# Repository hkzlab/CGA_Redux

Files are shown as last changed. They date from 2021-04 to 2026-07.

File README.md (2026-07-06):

# Color Graphics Adapter - Redux

## Introduction

The Color Graphics Adapter (**CGA**) Redux board is a more or less faithful clone of the original IBM CGA, based on the original schematics.

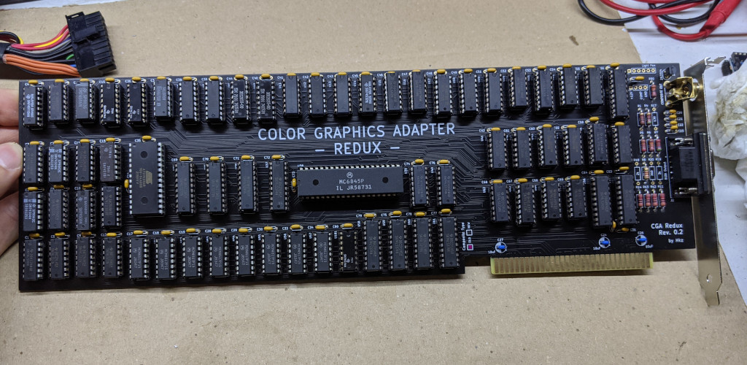
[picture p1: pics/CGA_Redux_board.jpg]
CGA Redux


Since revision 0.2 of this board, **You can decide to build it with the "new" or "old" style composite output**, giving you slightly different colours.

Have a look [HERE](https://int10h.org/blog/2015/08/8088-mph-final-old-vs-new-cga-gory-details/) for a blog post that discusses the difference in regard to the famous **8088MPH** demo!

### Disclaimer

I take NO responsibility for what happens if you decide to build and use this card. Your computer might crash, catch fire or be destroyed in other nasty ways.
You're encourauged to take what you deem fit from this, and use it in your projects!

### Functionalities

✅ means I tested the functionality and it works, ❌ means I tested the functionality and found issues, ? means that the functionality has yet to be tested.

* [✅] Digital display in text mode, 40 columns
* [✅] Digital display in text mode, 80 columns
* [✅] Composite display in text mode, 40 columns
* [✅] Composite display in text mode, 80 columns
* [✅] Graphics mode in digital
* [✅] Graphics mode in composite
* [✅] Run CheckIt video test
* [✅] 8088MPH Demo
* [?] Light pen input

## Bill of Materials

| Component | Qty | Type / Value |
| --- | --- | --- |
| **TODO** | | |

### Character ROM

This board needs a character ROM to work. I would advise to search for a dump of IBM P/N 5788005, concatenate it four times and burn it on a 27C256 EPROM.

### Component substitutions

* U4,U5 and U101 should all be 'S174s, but I had only 'LS174 available. The board looks to be working without issues anyway
* U50-U57 are all 120ns DRAMs in my original board. I had only 150ns chips for this build, and they worked fine
* U9,U10 are 74153 chips. I tried to replace them with 74LS153 chips by Texas Instruments with good results. **Needs some testing with colored screens**
* U50-U57 can be substituted by 41256 / 4164 DRAMs like the M5K4164 or HM4864P (the additional address lines are grounded). **Tested with HM4864P**

## Support

If you wish to support me in building new hardware and software for old machines, [throw a few euros in my direction via Ko-Fi](https://ko-fi.com/hkzlab) ☕!

### 💰 Selling these boards 💰

I you want to contact me about selling this project, you can reach me via email at `0hkzUNDERSCOREprojects6ATposteoDOTnet` after properly fixing the email address by removing the digits and replacing the uppercase words with the proper characters.

**Contacts via other channels will be ignored**, as it means you did not read this document thoroughly.

"Collaborations" will boil down to the following:

- If you wish to produce and share this project at a loss or at cost, go for it. I am only asking for attribution and to let me know via email.
- If you want to do it for profit, let's discuss it. I'll probably settle for a rough 5% of the profit. Importing components is getting more expensive by the day, so this will contribute to me making future projects available for free.
- I will NOT do customer assistance for you or your customers. This is a hobby, not my job.

If this is not ok for you, you're cordially invited to go bother someone else :)

Authorized sellers will be listed in this README. If you find someone selling my boards without being listed here, it means they're stealing other people's work.

## Known issues

### Rev 0

* The Composite video out has an inverted connection for that type of footprint. (fixed in rev 0.1)
* Silkscreen for U28 says 74LS10, but it's actually an 74S10 on an original board (fixed in rev 0.1)
* traces that connect the edge to the power planes for 5V and GND are a bit too thin for my taste (fixed in rev 0.1)

## TODO

* ???

## Credits

Thanks to [Sergey Kiselev](https://github.com/skiselev) for his symbol/footprint library!

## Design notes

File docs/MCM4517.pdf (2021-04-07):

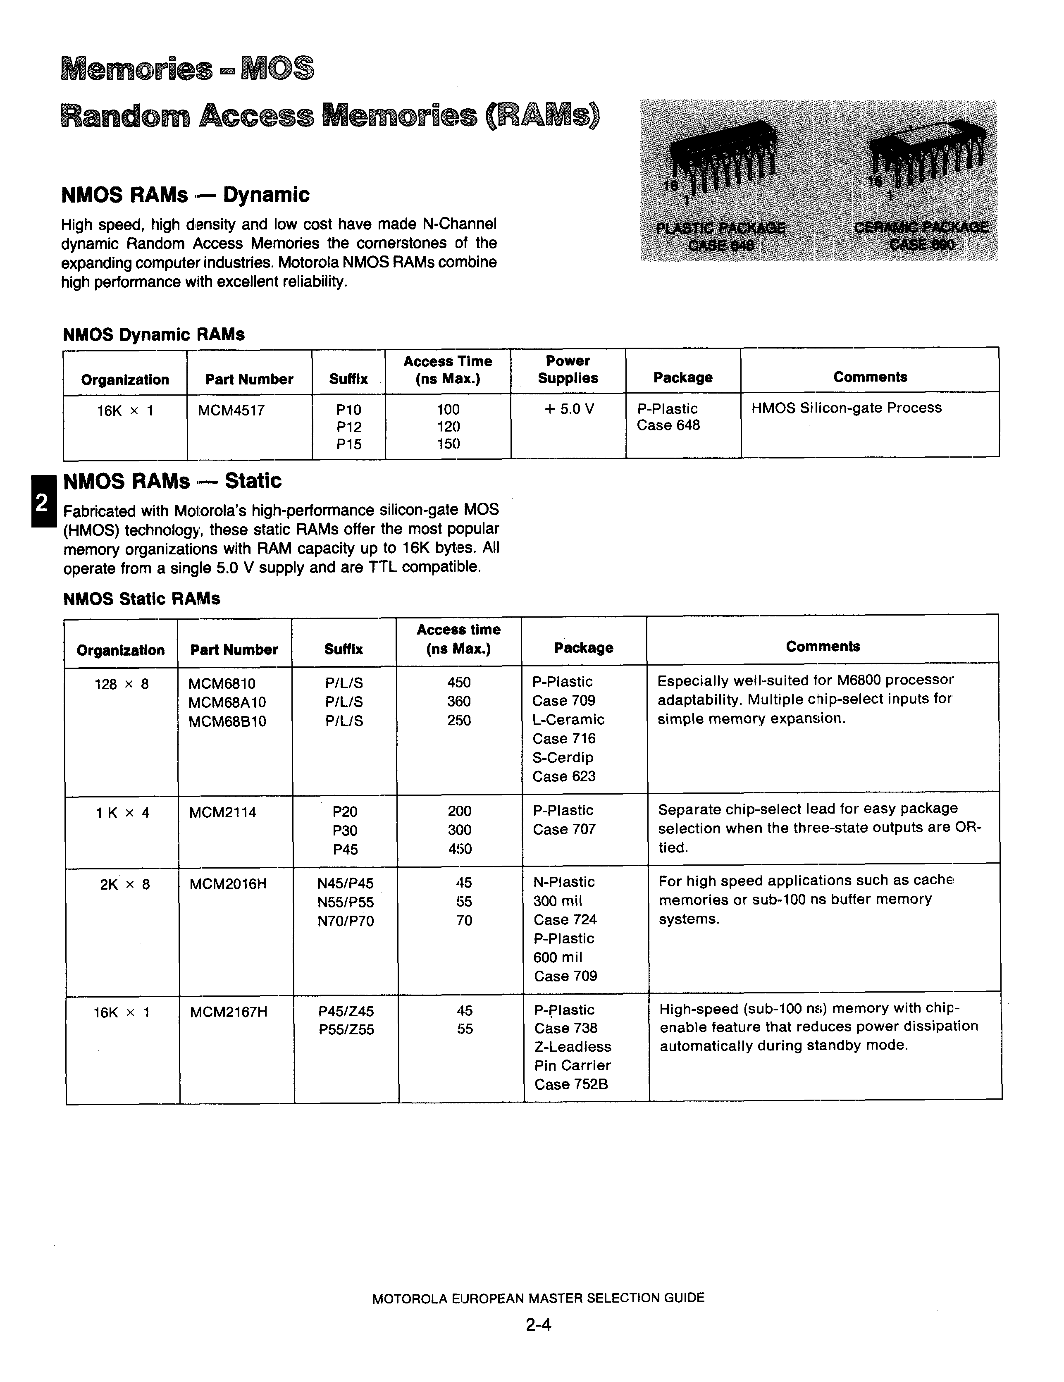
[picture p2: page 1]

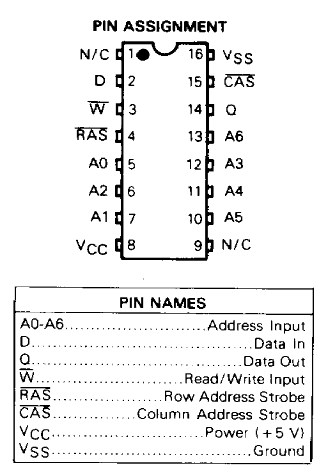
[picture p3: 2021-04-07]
docs/mcm4517pinout.png

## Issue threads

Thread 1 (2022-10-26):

The card bracket?

A-Small-Mice, 2022-10-26:
I need 3D printing the bracket data for the card..

hkzlab, 2022-10-26:
I did not design the bracket. Have a look at the following links for the measurements.

https://www.mouser.it/ProductDetail/Keystone-Electronics/9200-1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
https://www.mouser.it/datasheet/2/215/200-1-741899.pdf

I drilled the hole for the composite connector myself. You'll have to obtain precise measurements for that using either a gerber viewer or from inside kicad by opening the pcb files.

Closed 2022-10-26.

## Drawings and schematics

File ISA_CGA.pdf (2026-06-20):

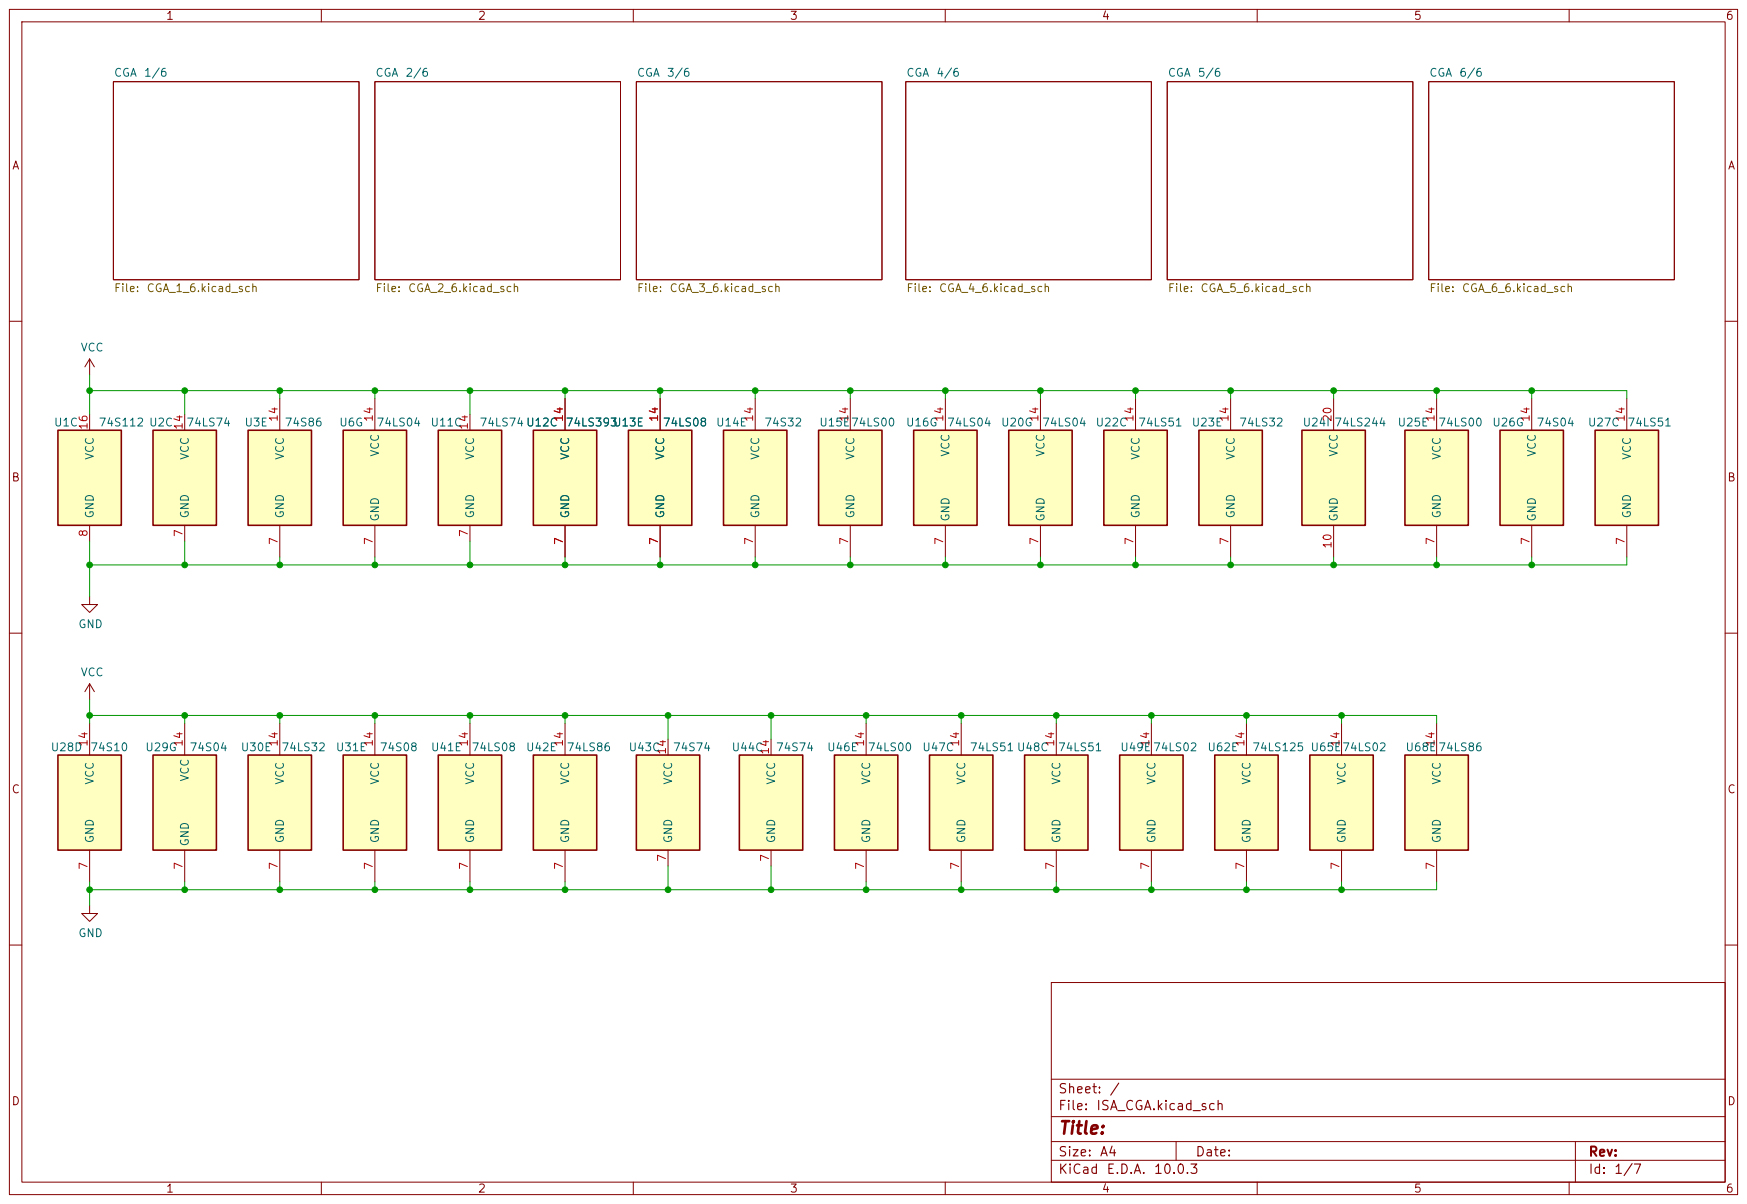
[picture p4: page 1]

7 VCC 14 U25E 74LS00 GND 10 VCC 20 U24I 74LS244 GND

Size: A4 | Rev:
KiCad E.D.A. 10.0.3 | Id: 1/7

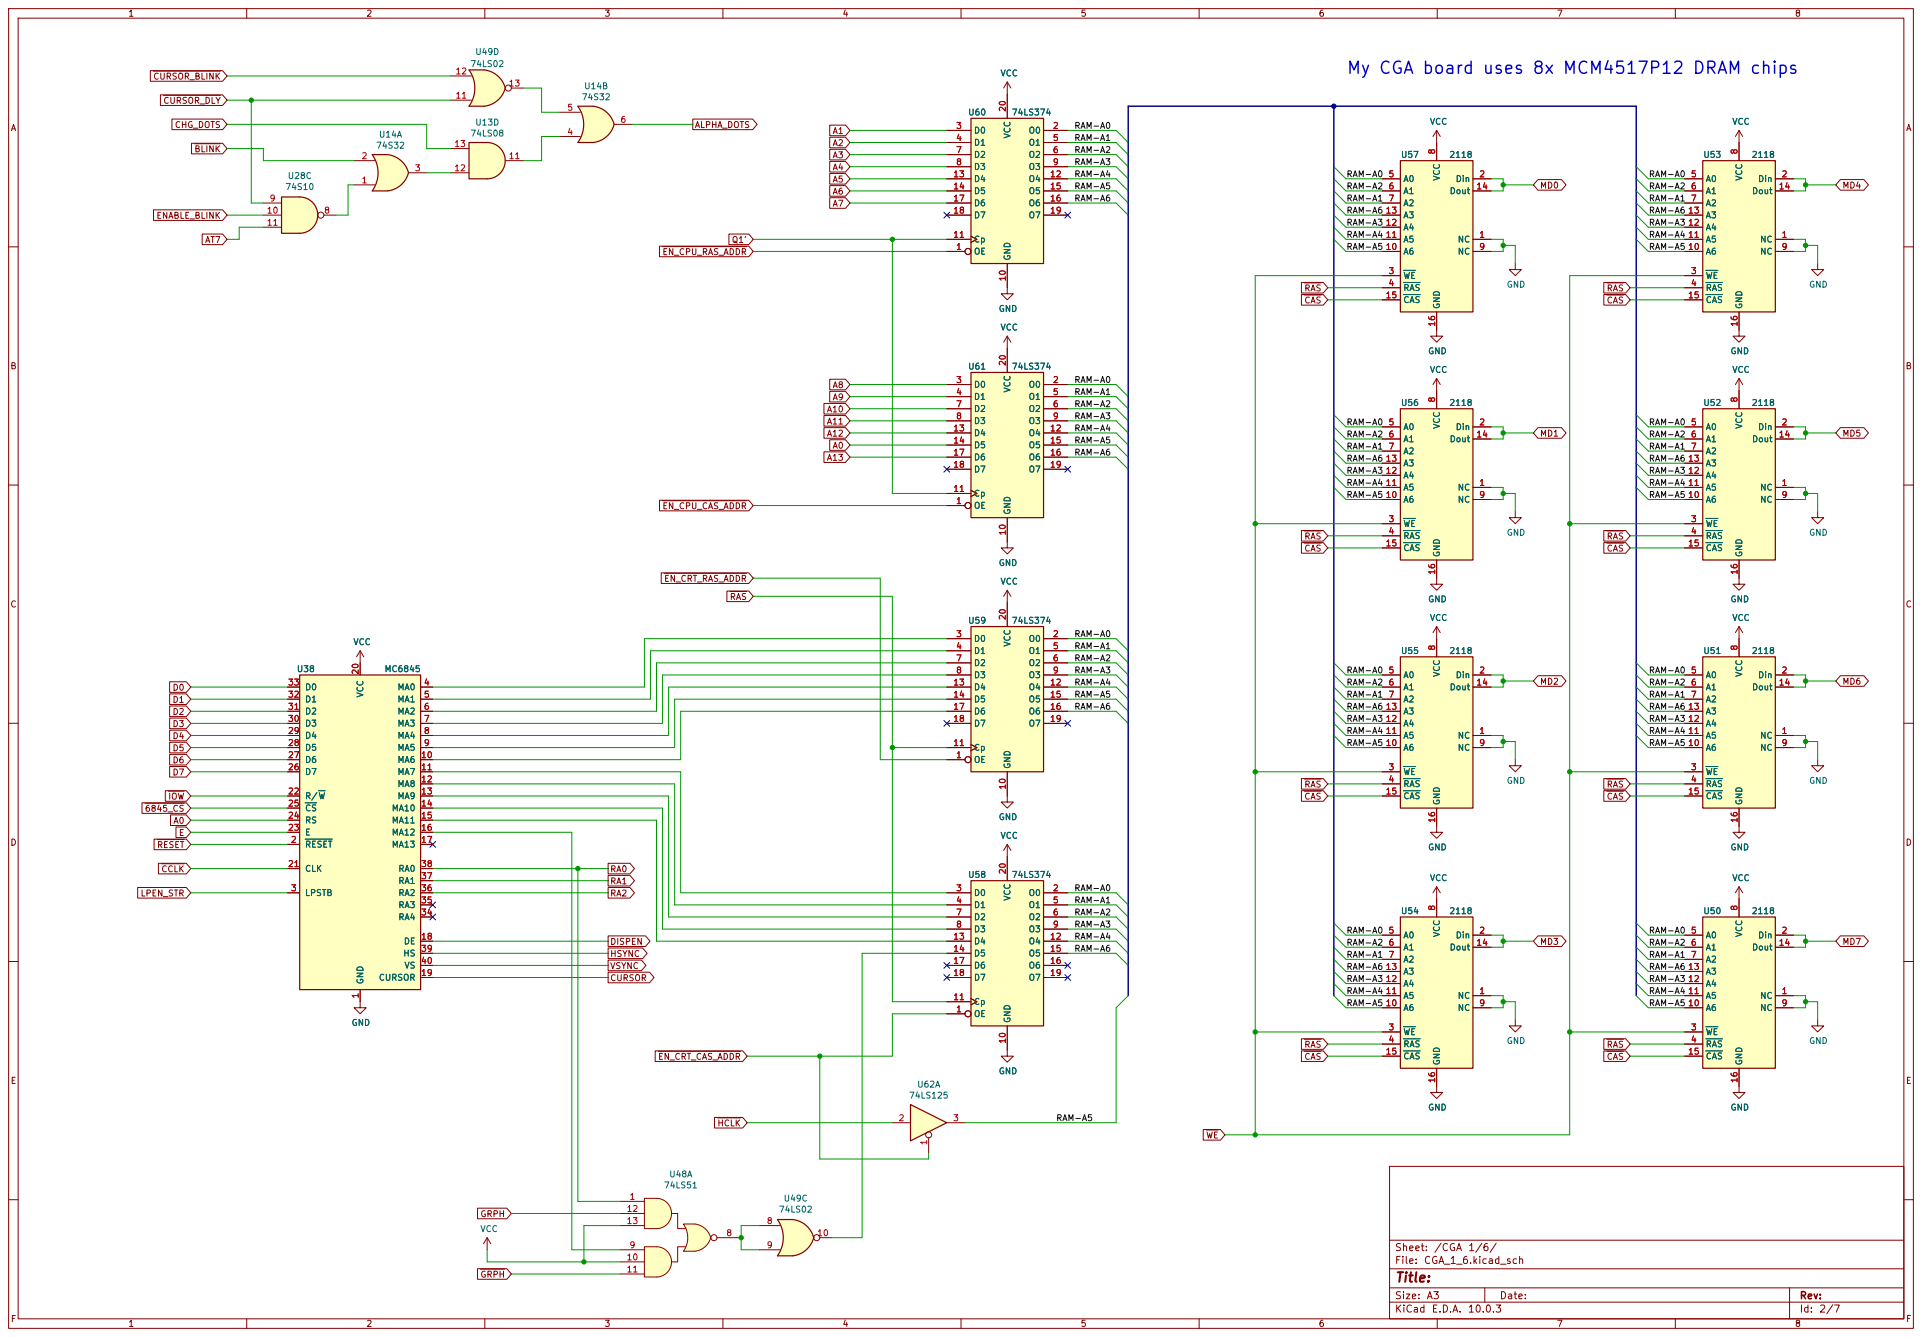
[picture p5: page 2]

RAM-A1 RAM-A6 RAM-A1 RAM-A5 RAM-A4 RAM-A6 RAM-A1 RAM-A5 RAM-A4 RAM-A5 RAM-A1 RAM-A3

GND
RAM-A3 RAM-A2 RAM-A0 RAM-A6 RAM-A3

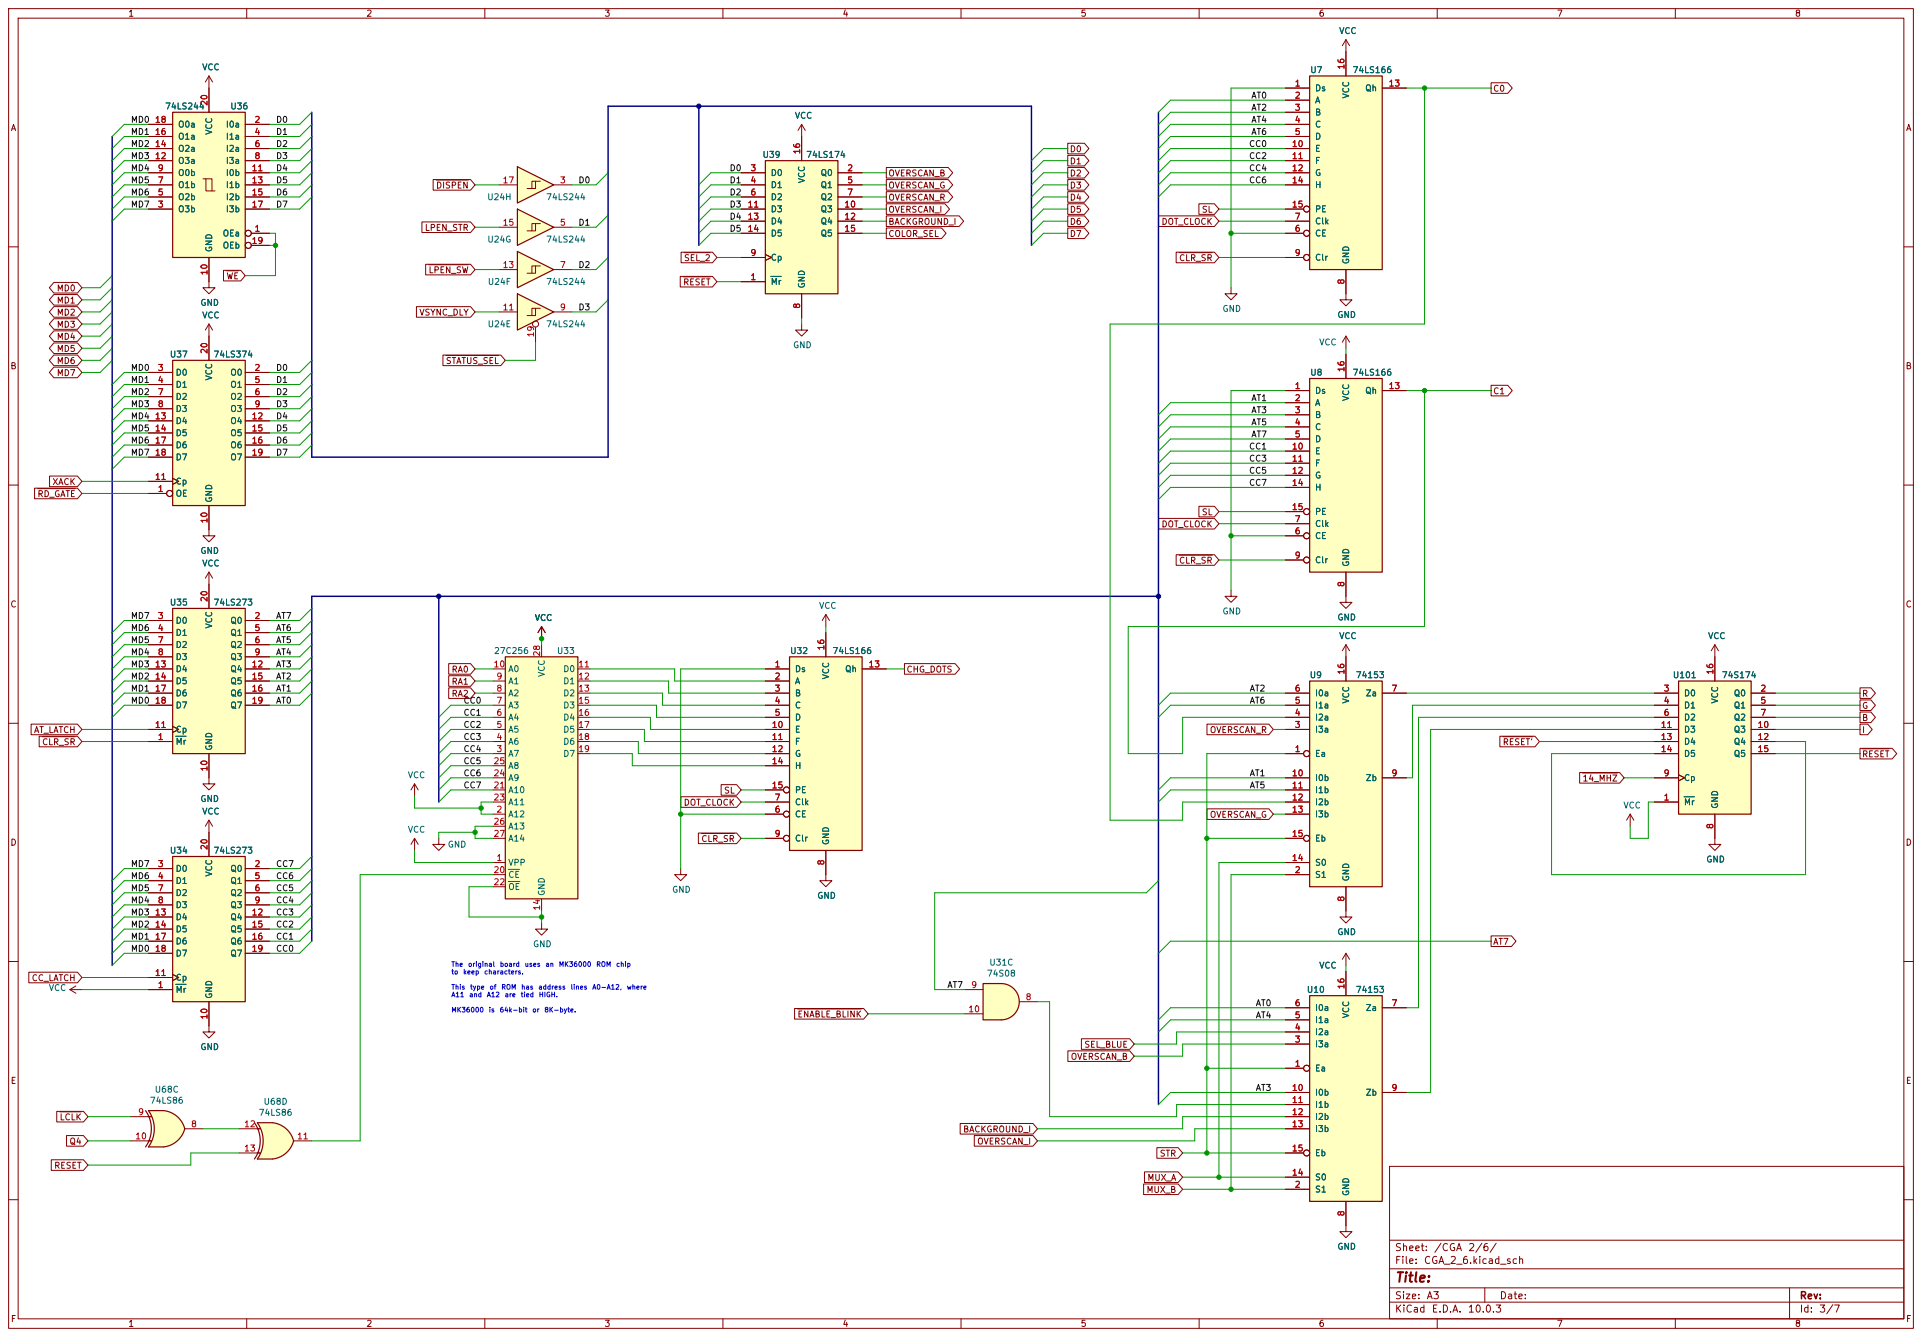
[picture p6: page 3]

The original board uses an MK36000 ROM chip
to keep characters. This type of ROM has address lines A0-A12, where

A11 and A12 are tied HIGH. MK36000 is 64k-bit or 8K-byte.

I2b 12
I3b 13

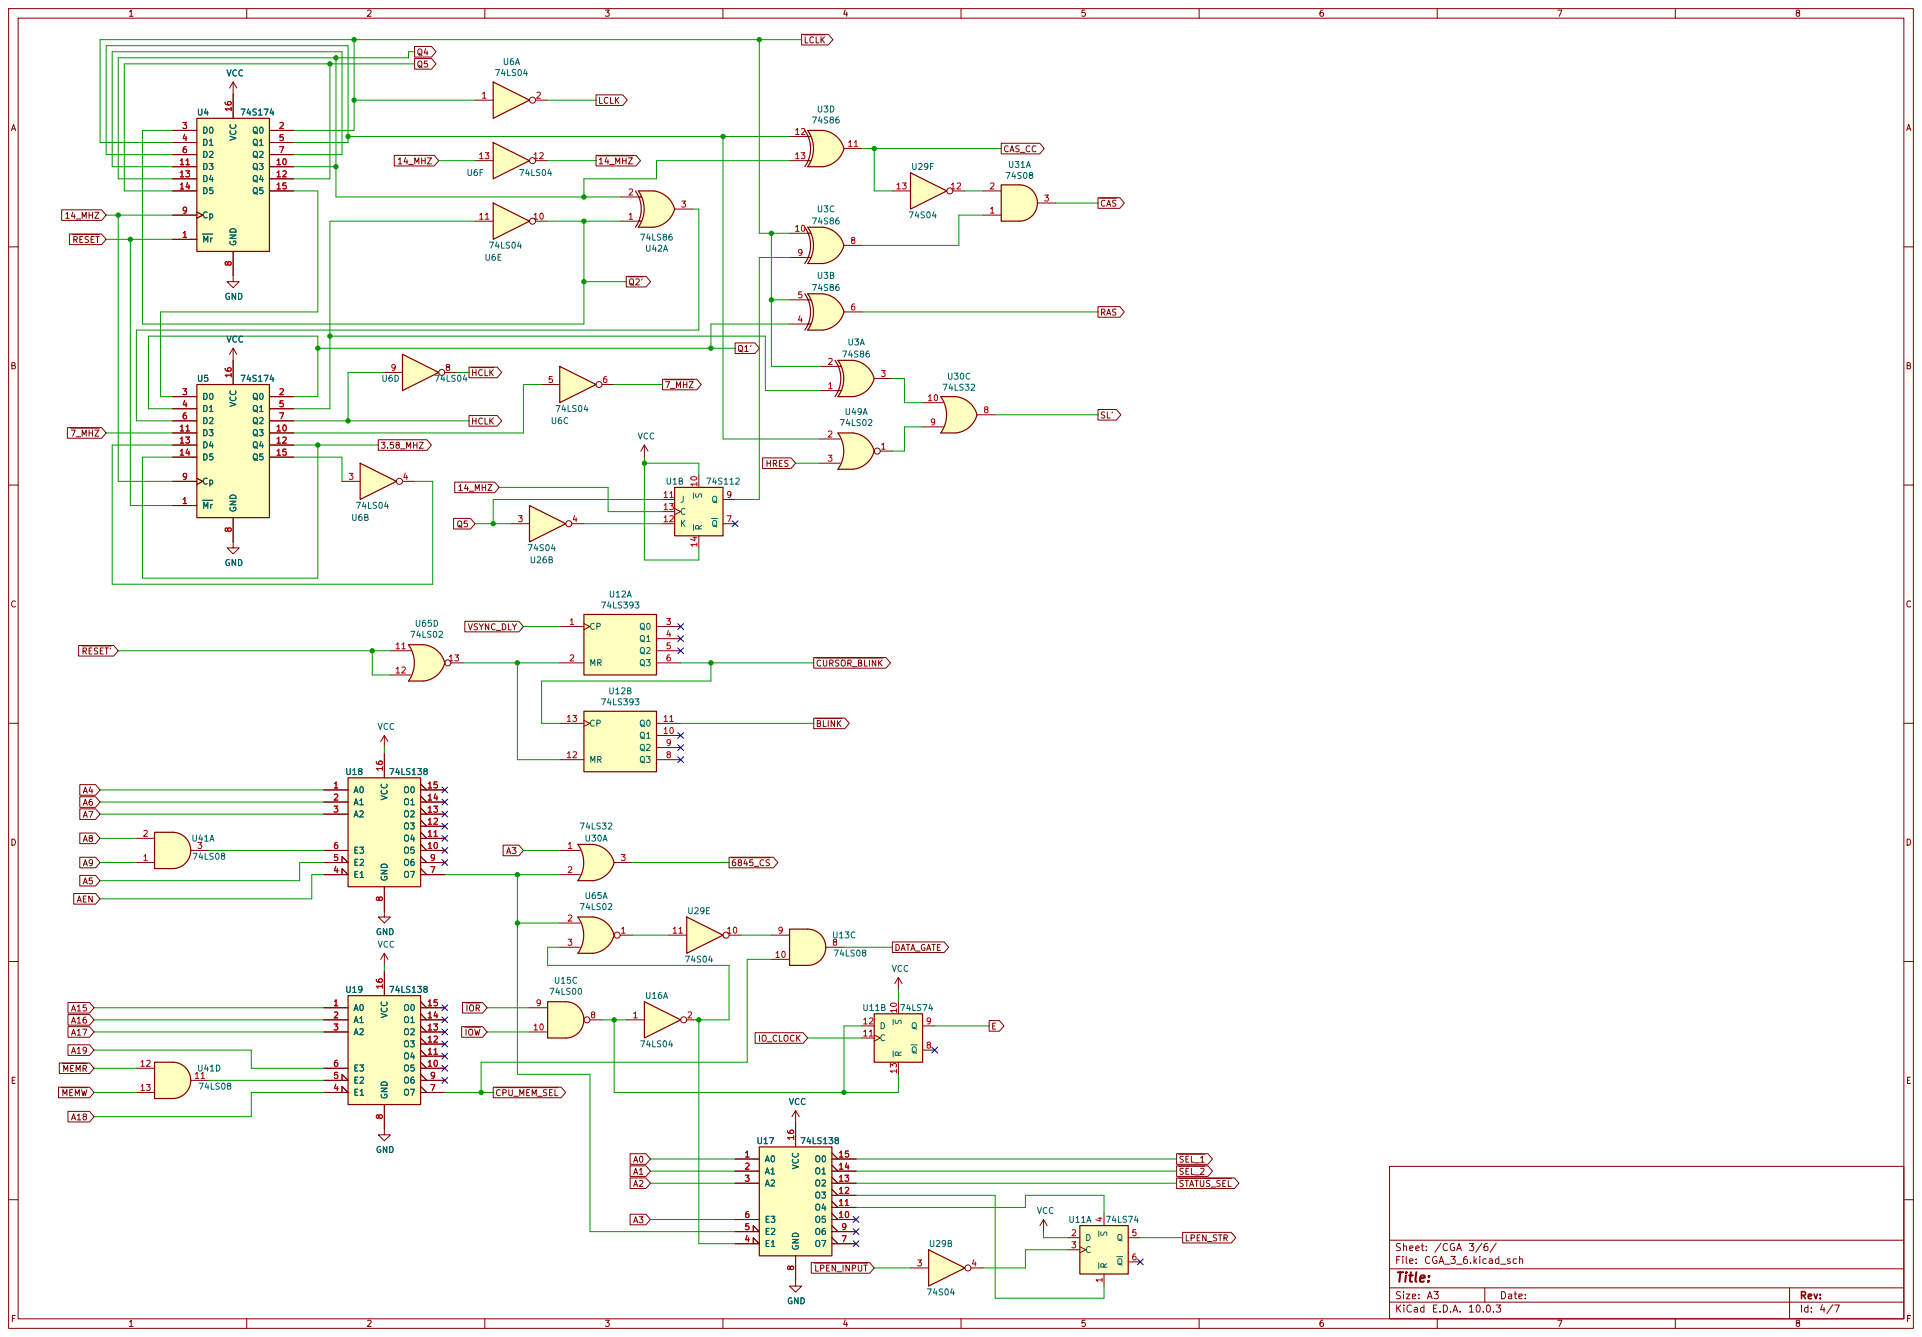
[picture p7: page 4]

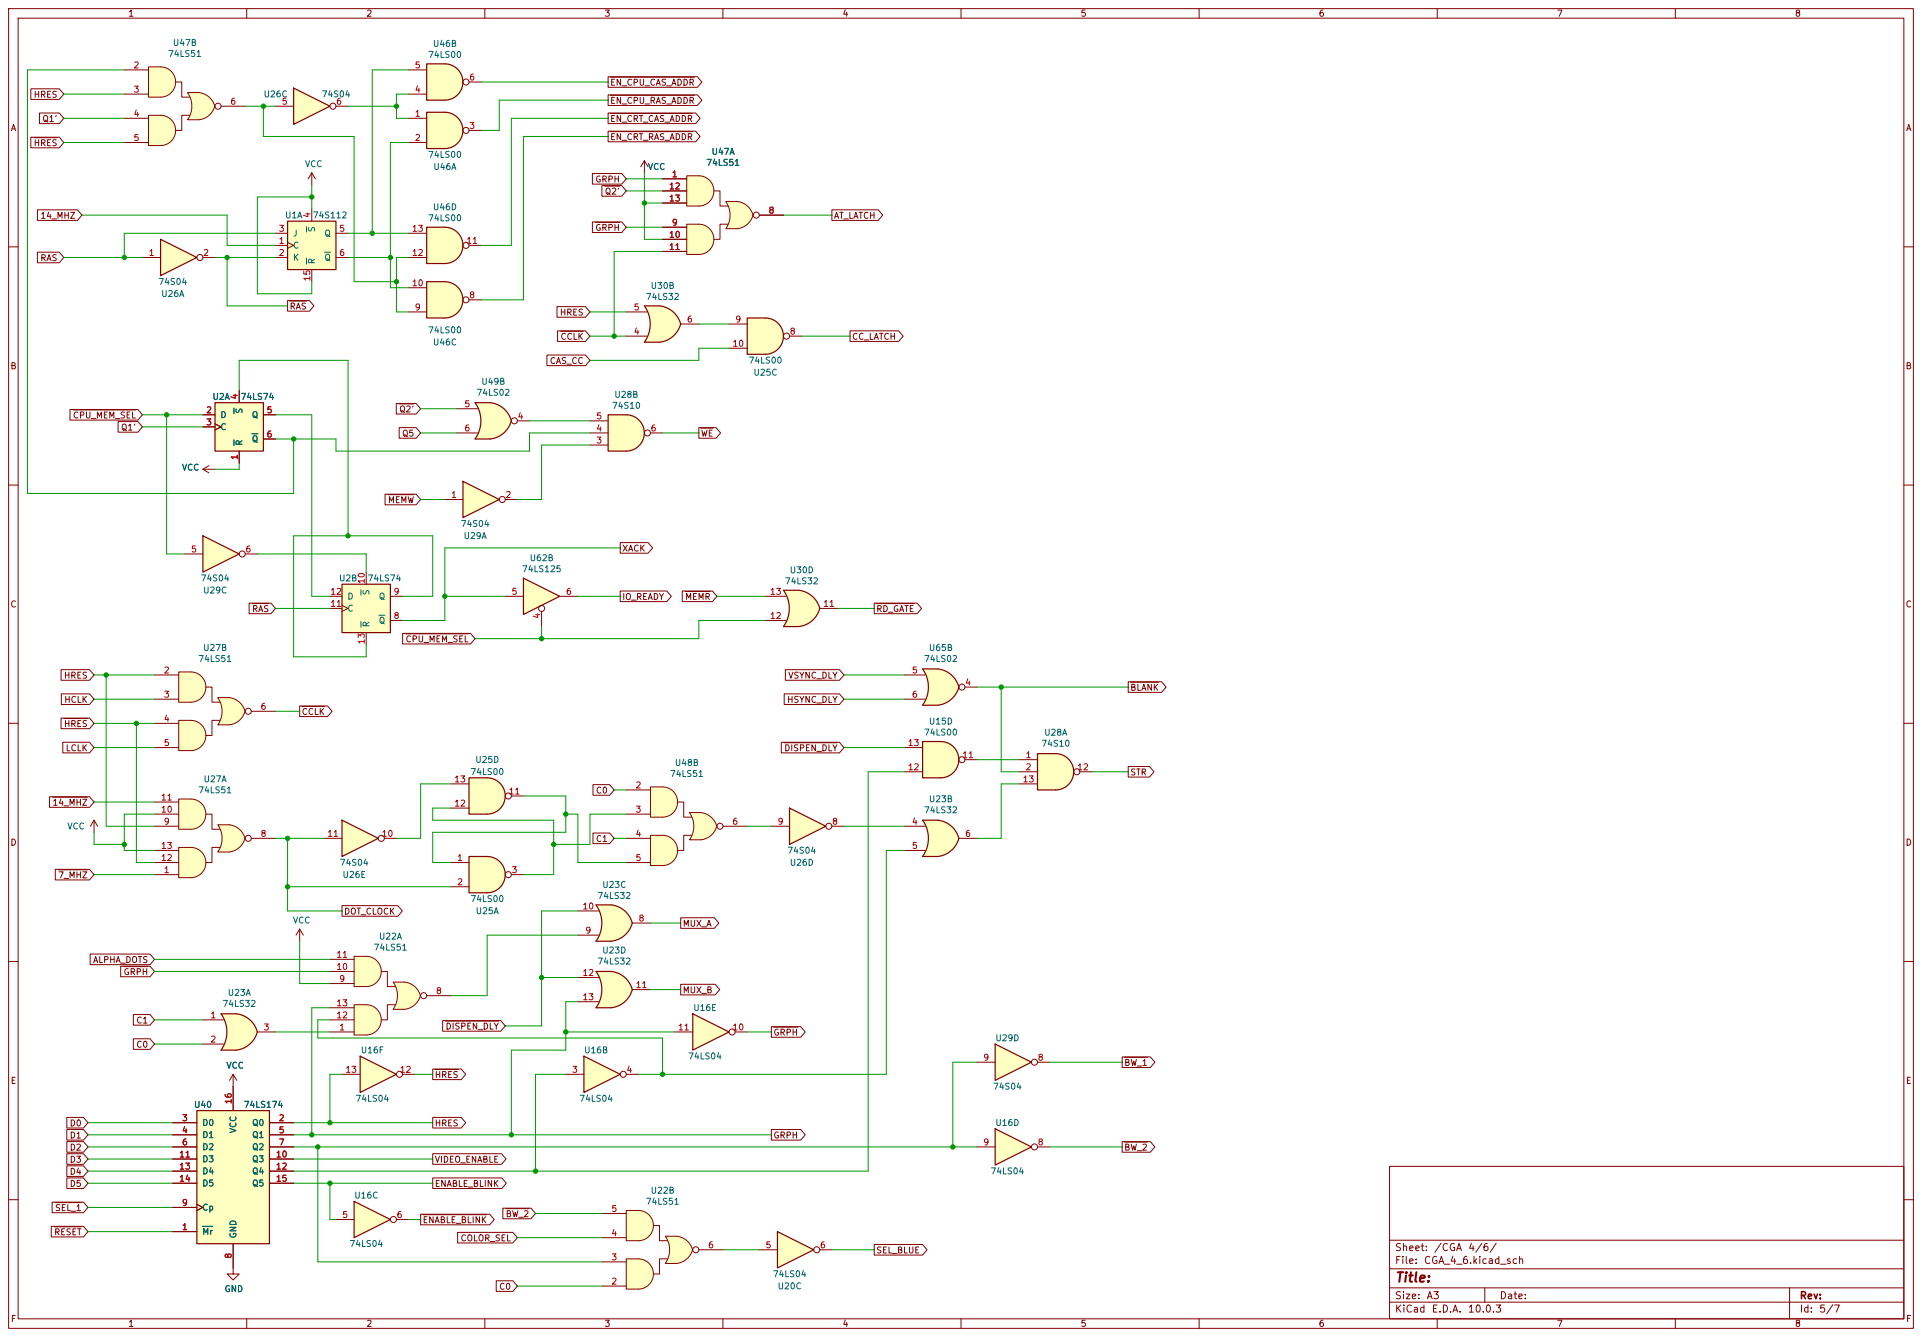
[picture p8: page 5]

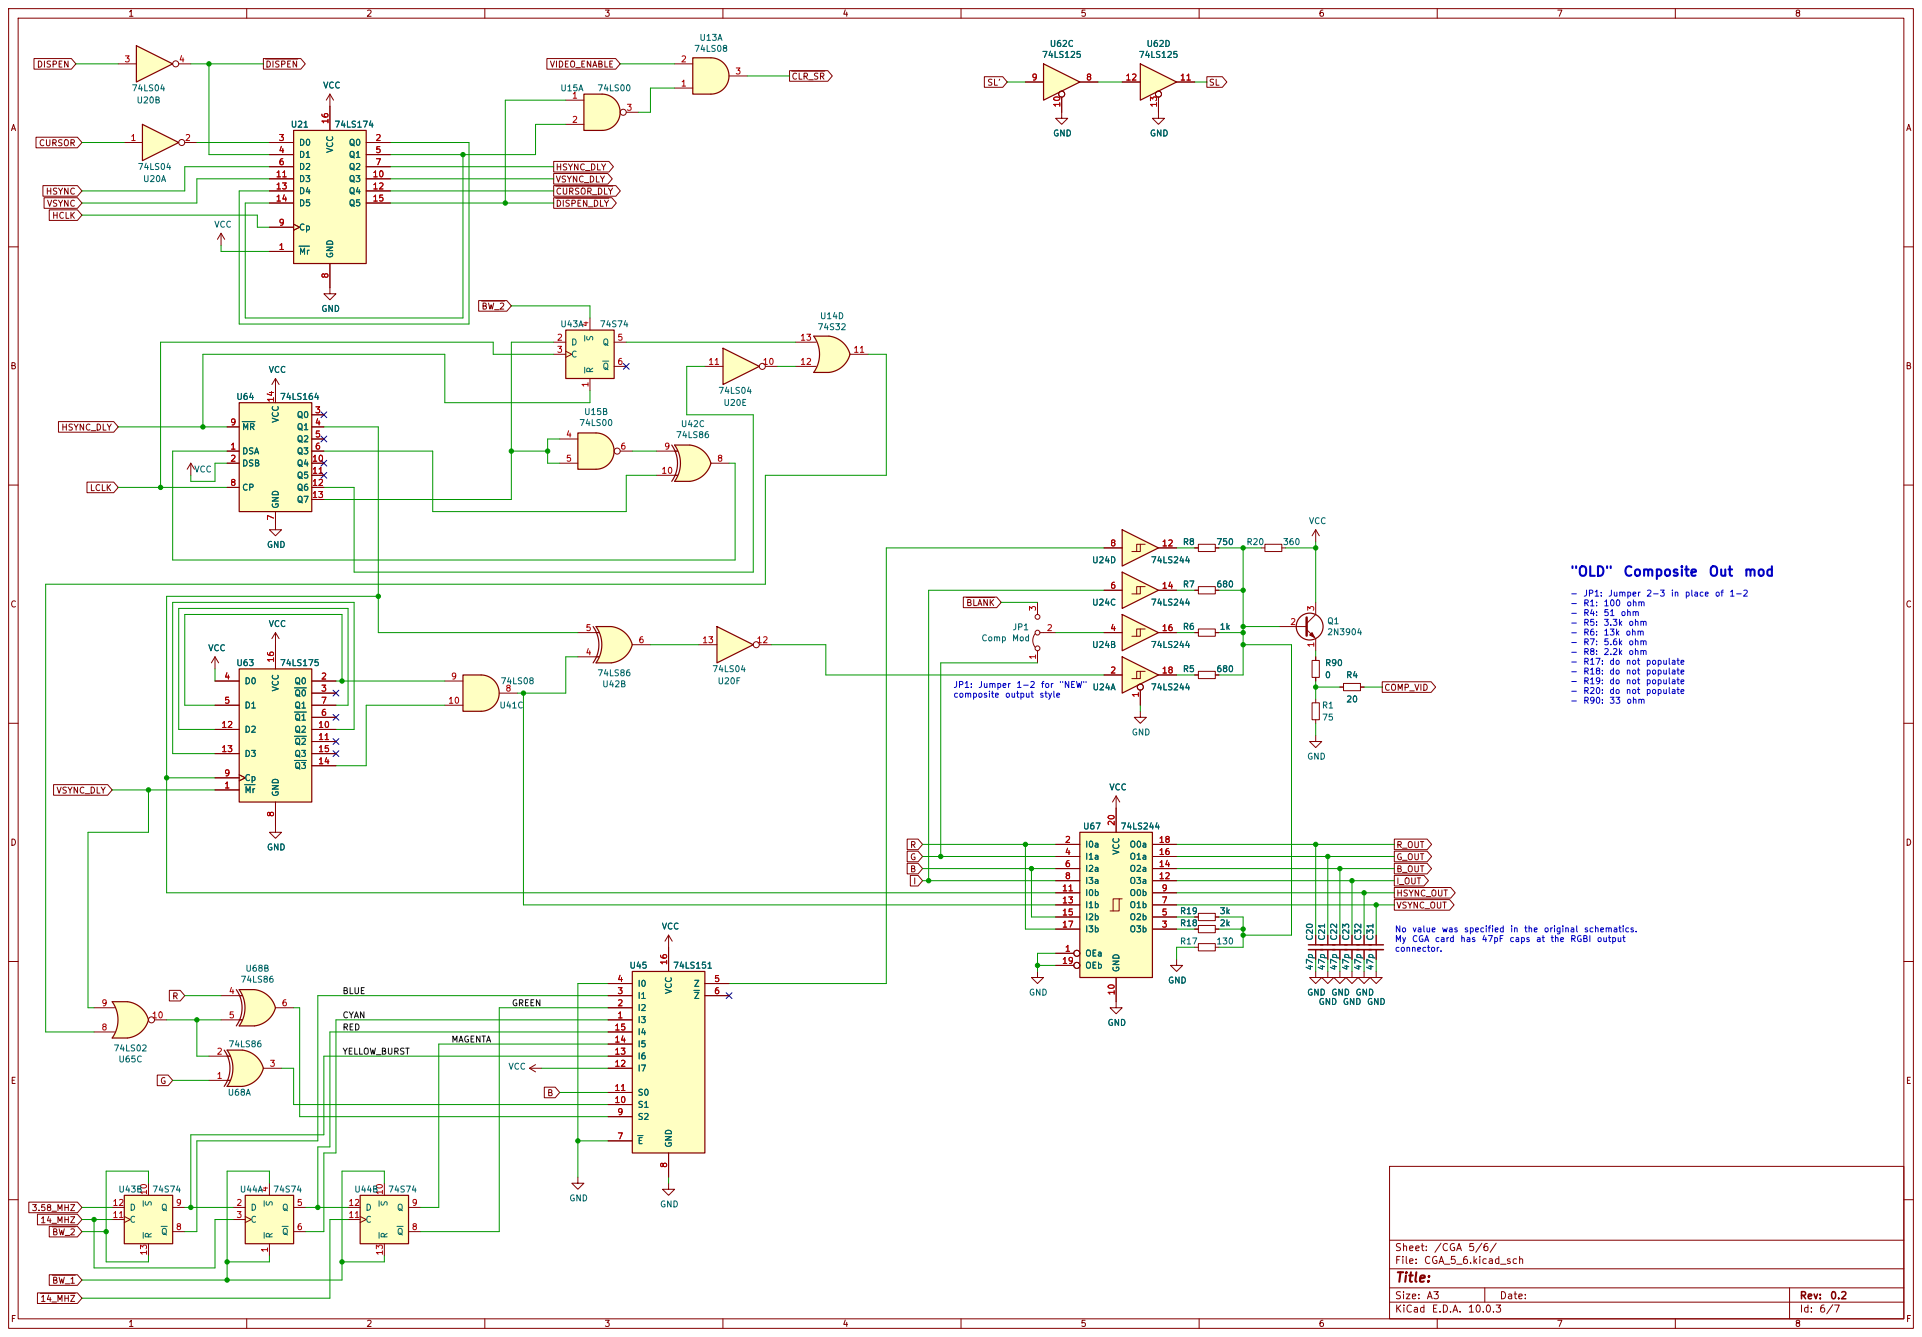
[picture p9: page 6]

7 CP 8 MR 9 Q4 10 Q5 11 Q6 12 Q7 13 VCC 14 GND U45 74LS151

"OLD" Composite Out mod

- R4: 51 ohm
- R5: 3.3k ohm
- R6: 13k ohm
- R7: 5.6k ohm
- R8: 2.2k ohm
- R17: do not populate - R18: do not populate - R19: do not populate - R20: do not populate - R90: 33 ohm

VCC
GND U67 74LS244 OEa 1

RED MAGENTA

VCC | S1 10 S0 11

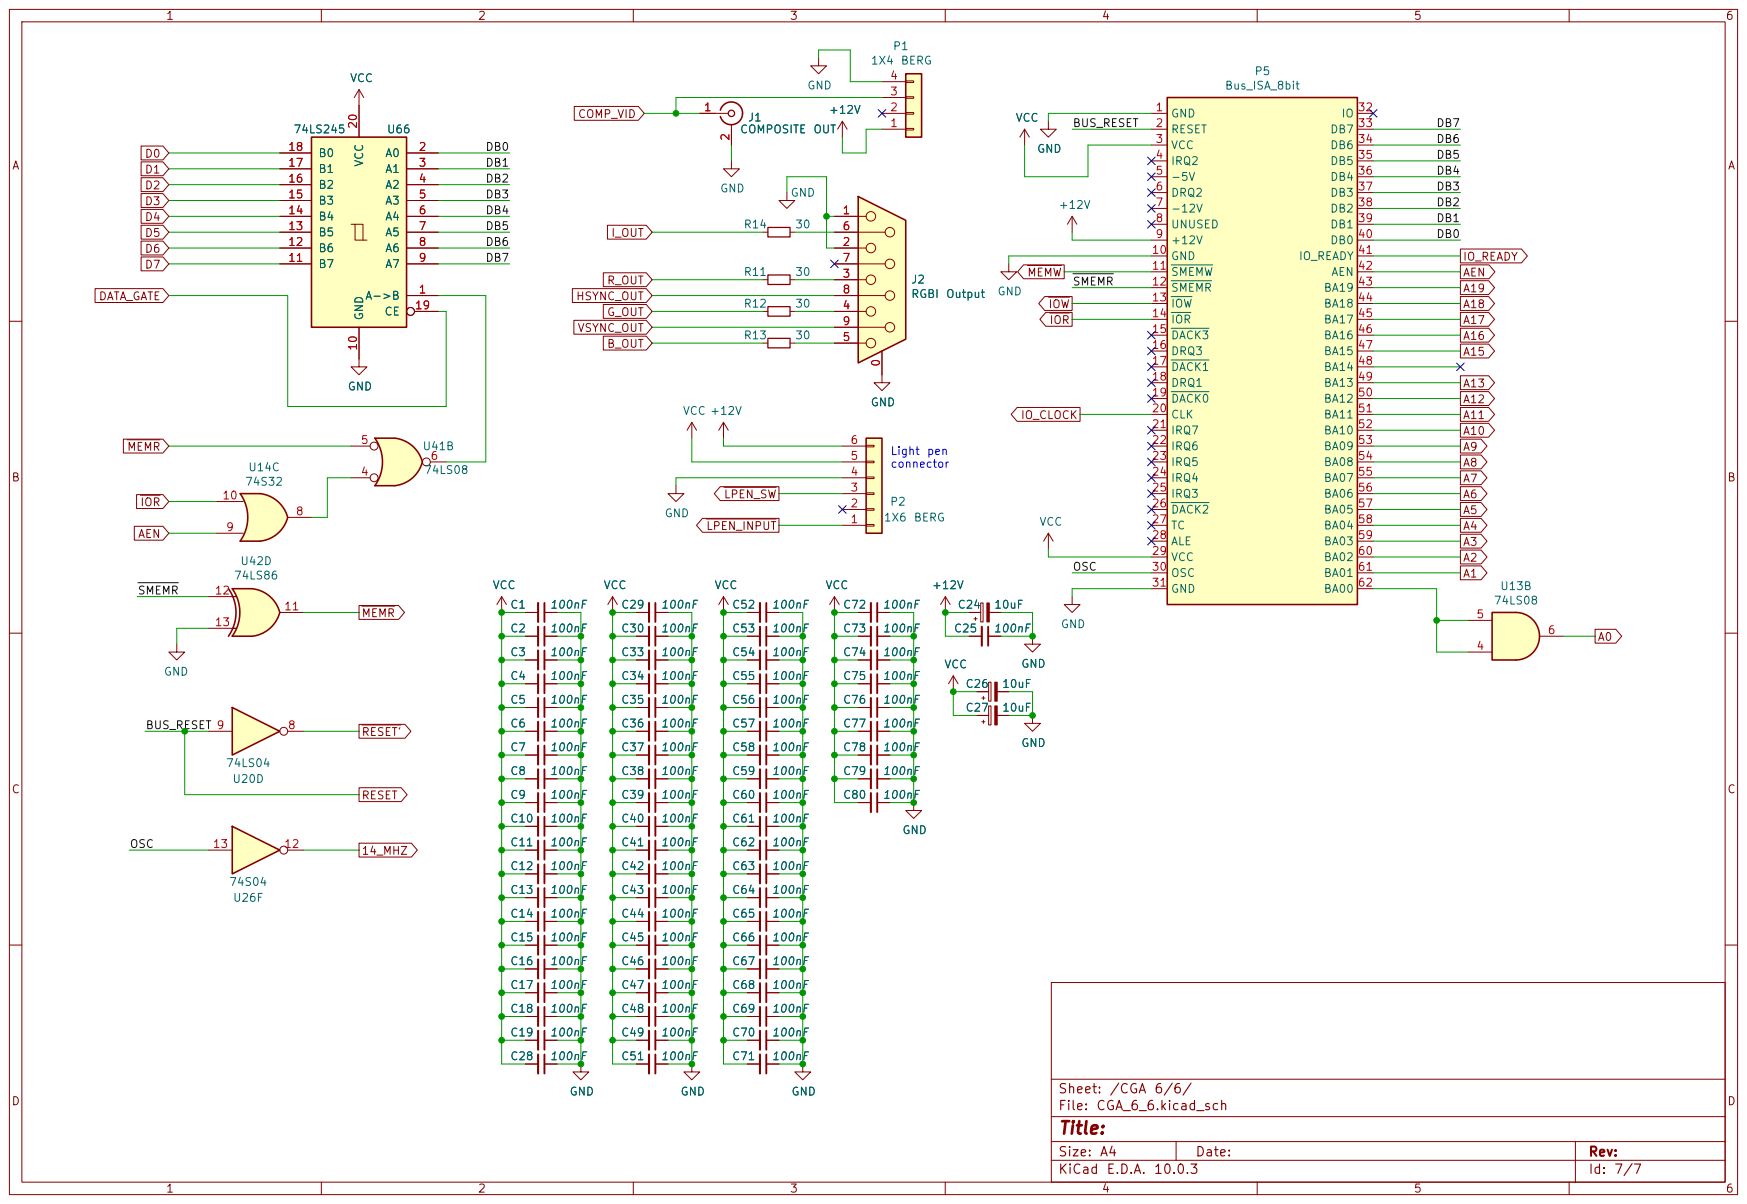
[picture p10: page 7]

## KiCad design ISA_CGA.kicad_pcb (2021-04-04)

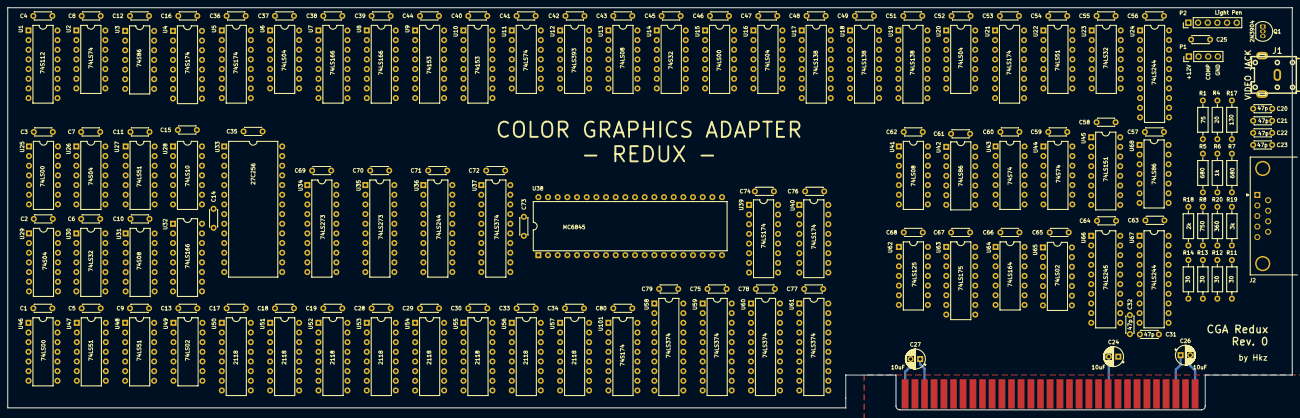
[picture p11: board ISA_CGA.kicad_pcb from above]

Board: 4 copper layers, 337.6 x 105.7 mm, 168 parts (0 on the bottom side), 300 nets.

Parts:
C1, C2, C3, C4, C5, C6, C7, C8, C9, C10, C11, C12, C13, C14, C15, C16, C17, C18, C19, C25, C28, C29, C30, C33, C34, C35, C36, C37, C38, C39, C40, C41, C42, C43, C44, C45, C46, C47, C48, C49, C51, C52, C53, C54, C55, C56, C57, C58, C59, C60, C61, C62, C63, C64, C65, C66, C67, C68, C69, C70, C71, C72, C73, C74, C75, C76, C77, C78, C79, C80: 100nF; C_Disc_D4.3mm_W1.9mm_P5.00mm
C20, C21, C22, C23, C31, C32: 47p; C_Disc_D4.3mm_W1.9mm_P5.00mm
C24, C26, C27: 10uF; CP_Radial_D5.0mm_P2.50mm
J1: VIDEO JACK; rca_yellow
J2: RGBI Output; DSUB-9_Female_Horizontal_P2.77x2.84mm_EdgePinOffset7.70mm_H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
P1: 1X4 BERG; PinHeader_1x04_P2.54mm_Vertical
P2: 1X6 BERG; PinHeader_1x06_P2.54mm_Vertical
P5: Bus_ISA_8bit; Conn_Edge_PCB_ISA8
Q1: 2N3904; TO-92_Inline
R1: 75; R_Axial_DIN0207_L6.3mm_D2.5mm_P10.16mm_Horizontal
R4: 20; R_Axial_DIN0207_L6.3mm_D2.5mm_P10.16mm_Horizontal
R5, R7: 680; R_Axial_DIN0207_L6.3mm_D2.5mm_P10.16mm_Horizontal
R6: 1k; R_Axial_DIN0207_L6.3mm_D2.5mm_P10.16mm_Horizontal
R8: 750; R_Axial_DIN0207_L6.3mm_D2.5mm_P10.16mm_Horizontal
R11, R12, R13, R14: 30; R_Axial_DIN0207_L6.3mm_D2.5mm_P10.16mm_Horizontal
R17: 130; R_Axial_DIN0207_L6.3mm_D2.5mm_P10.16mm_Horizontal
R18: 2k; R_Axial_DIN0207_L6.3mm_D2.5mm_P10.16mm_Horizontal
R19: 3k; R_Axial_DIN0207_L6.3mm_D2.5mm_P10.16mm_Horizontal
R20: 360; R_Axial_DIN0207_L6.3mm_D2.5mm_P10.16mm_Horizontal
U1: 74S112; DIP-16_W7.62mm
U2, U11: 74LS74; DIP-14_W7.62mm
U3: 74S86; DIP-14_W7.62mm
U4, U5, U101: 74S174; DIP-16_W7.62mm
U6, U16, U20: 74LS04; DIP-14_W7.62mm
U7, U8, U32: 74LS166; DIP-16_W7.62mm
U9, U10: 74153; DIP-16_W7.62mm
U12: 74LS393; DIP-14_W7.62mm
U13, U41: 74LS08; DIP-14_W7.62mm
U14: 74S32; DIP-14_W7.62mm
U15, U25, U46: 74LS00; DIP-14_W7.62mm
U17, U18, U19: 74LS138; DIP-16_W7.62mm
U21, U39, U40: 74LS174; DIP-16_W7.62mm
U22, U27, U47, U48: 74LS51; DIP-14_W7.62mm
U23, U30: 74LS32; DIP-14_W7.62mm
U24, U36, U67: 74LS244; DIP-20_W7.62mm
U26, U29: 74S04; DIP-14_W7.62mm
U28: 74LS10; DIP-14_W7.62mm
U31: 74S08; DIP-14_W7.62mm
U33: 27C256; DIP-28_W15.24mm
U34, U35: 74LS273; DIP-20_W7.62mm
U37, U58, U59, U60, U61: 74LS374; DIP-20_W7.62mm
U38: MC6845; DIP-40_W15.24mm
U42, U68: 74LS86; DIP-14_W7.62mm
U43, U44: 74S74; DIP-14_W7.62mm
U45: 74LS151; DIP-16_W7.62mm
U49, U65: 74LS02; DIP-14_W7.62mm
U50, U51, U52, U53, U54, U55, U56, U57: 2118; DIP-16_W7.62mm
U62: 74LS125; DIP-14_W7.62mm
U63: 74LS175; DIP-16_W7.62mm
U64: 74LS164; DIP-14_W7.62mm
U66: 74LS245; DIP-20_W7.62mm

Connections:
3.58_MHZ: U5.12, U5.14, U43.12
14_MHZ: U1.1, U1.13, U4.9, U5.9, U6.13, U26.12, U43.11, U44.3
+12V: C24.1, C25.2, P1.1, P2.6, P5.9
/CGA 1/6/RAM-A0: U50.5, U51.5, U52.5, U53.5, U54.5, U55.5, U56.5, U57.5, U58.2, U59.2, U60.2, U61.2
/CGA 1/6/RAM-A1: U50.7, U51.7, U52.7, U53.7, U54.7, U55.7, U56.7, U57.7, U58.5, U59.5, U60.5, U61.5
/CGA 1/6/RAM-A2: U50.6, U51.6, U52.6, U53.6, U54.6, U55.6, U56.6, U57.6, U58.6, U59.6, U60.6, U61.6
/CGA 1/6/RAM-A3: U50.12, U51.12, U52.12, U53.12, U54.12, U55.12, U56.12, U57.12, U58.9, U59.9, U60.9, U61.9
/CGA 1/6/RAM-A4: U50.11, U51.11, U52.11, U53.11, U54.11, U55.11, U56.11, U57.11, U58.12, U59.12, U60.12, U61.12
/CGA 1/6/RAM-A5: U50.10, U51.10, U52.10, U53.10, U54.10, U55.10, U56.10, U57.10, U59.15, U60.15, U61.15, U62.3
/CGA 1/6/RAM-A6: U50.13, U51.13, U52.13, U53.13, U54.13, U55.13, U56.13, U57.13, U58.15, U59.16, U60.16, U61.16
/CGA 2/6/AT0: U7.2, U10.6, U35.19
/CGA 2/6/AT1: U8.2, U9.10, U35.16
/CGA 2/6/AT2: U7.3, U9.6, U35.15
/CGA 2/6/AT3: U8.3, U10.10, U35.12
/CGA 2/6/AT4: U7.4, U10.5, U35.9
/CGA 2/6/AT5: U8.4, U9.11, U35.6
/CGA 2/6/AT6: U7.5, U9.5, U35.5
/CGA 2/6/CC0: U7.10, U33.7, U34.19
/CGA 2/6/CC1: U8.10, U33.6, U34.16
/CGA 2/6/CC2: U7.11, U33.5, U34.15
/CGA 2/6/CC3: U8.11, U33.4, U34.12
/CGA 2/6/CC4: U7.12, U33.3, U34.9
/CGA 2/6/CC5: U8.12, U33.25, U34.6
/CGA 2/6/CC6: U7.14, U33.24, U34.5
/CGA 2/6/CC7: U8.14, U33.21, U34.2
/CGA 5/6/BLUE: U43.8, U45.3
/CGA 5/6/CYAN: U44.6, U45.1
/CGA 5/6/GREEN: U44.8, U45.2
/CGA 5/6/MAGENTA: U44.9, U45.14
/CGA 5/6/RED: U44.5, U44.12, U45.15
/CGA 5/6/YELLOW_BURST: U43.9, U44.2, U45.13
/CGA 6/6/DB0: P5.40, U66.2
/CGA 6/6/DB1: P5.39, U66.3
/CGA 6/6/DB2: P5.38, U66.4
/CGA 6/6/DB3: P5.37, U66.5
/CGA 6/6/DB4: P5.36, U66.6
/CGA 6/6/DB5: P5.35, U66.7
/CGA 6/6/DB6: P5.34, U66.8
/CGA 6/6/DB7: P5.33, U66.9
/CGA 6/6/OSC: P5.30, U26.13
/CGA 6/6/~SMEMR: P5.12, U42.12
A0: U13.6, U17.1, U38.24, U61.14
A1: P5.61, U17.2, U60.3
A2: P5.60, U17.3, U60.4
A3: P5.59, U17.6, U30.1, U60.7
A4: P5.58, U18.1, U60.8
A5: P5.57, U18.5, U60.13
A6: P5.56, U18.2, U60.14
A7: P5.55, U18.3, U60.17
A8: P5.54, U41.2, U61.3
A9: P5.53, U41.1, U61.4
A10: P5.52, U61.7
A11: P5.51, U61.8
A12: P5.50, U61.13
A13: P5.49, U61.17
A15: P5.47, U19.1
A16: P5.46, U19.2
A17: P5.45, U19.3
A18: P5.44, U19.4
A19: P5.43, U19.6
AEN: P5.42, U14.9, U18.4
ALPHA_DOTS: U14.6, U22.11
AT7: U8.5, U28.11, U31.9, U35.2
AT_LATCH: U35.11, U47.8
B: U45.11, U67.6, U67.15, U101.7
BACKGROUND_I: U10.12, U39.12
B_OUT: C22.1, R13.2, U67.14
C0: U7.13, U9.12, U22.2, U23.2, U48.2
C1: U8.13, U9.4, U23.1, U48.4
CAS_CC: U3.11, U25.10, U29.13
CC_LATCH: U25.8, U34.11
CHG_DOTS: U13.13, U32.13
COLOR_SEL: U22.4, U39.15
COMP_VID: J1.1, P1.3, R4.1
CURSOR: U20.1, U38.19
D0: U24.3, U36.2, U37.2, U38.33, U39.3, U40.3, U66.18
D1: U24.5, U36.4, U37.5, U38.32, U39.4, U40.4, U66.17
D2: U24.7, U36.6, U37.6, U38.31, U39.6, U40.6, U66.16
D3: U24.9, U36.8, U37.9, U38.30, U39.11, U40.11, U66.15
D4: U36.11, U37.12, U38.29, U39.13, U40.13, U66.14
D5: U36.13, U37.15, U38.28, U39.14, U40.14, U66.13
D6: U36.15, U37.16, U38.27, U66.12
D7: U36.17, U37.19, U38.26, U66.11
DATA_GATE: U13.8, U66.19
DISPEN: U20.3, U38.18
DOT_CLOCK: U7.7, U8.7, U25.2, U26.11, U27.8, U32.7
E: U11.9, U38.23
ENABLE_BLINK: U16.5, U28.10, U40.15
G: U24.4, U67.4, U68.1, U101.5
GND: C1.1, C2.1, C3.1, C4.1, C5.1, C6.1, C7.1, C8.1, C9.1, C10.1, C11.1, C12.1, C13.1, C14.1, C15.1, C16.1, C17.1, C18.1, C19.1, C20.2, C21.2, C22.2, C23.2, C24.2, C25.1, C26.2, C27.2, C28.1, C29.1, C30.1, C31.2, C32.2, C33.1, C34.1, C35.1, C36.1, C37.1, C38.1, C39.1, C40.1, C41.1, C42.1, C43.1, C44.1, C45.1, C46.1, C47.1, C48.1, C49.1, C51.1, C52.1, C53.1, C54.1, C55.1, C56.1, C57.1, C58.1, C59.1, C60.1, C61.1, C62.1, C63.1, C64.1, C65.1, C66.1, C67.1, C68.1, C69.1, C70.1, C71.1, C72.1, C73.1, C74.1, C75.1, C76.1, C77.1, C78.1, C79.1, C80.1, J1.2, J2.0, J2.1, J2.2, P1.4, P2.4, P5.1, P5.10, P5.31, R1.1, R17.2, U1.8, U2.7, U3.7, U4.8, U5.8, U6.7, U7.1, U7.6, U7.8, U8.1, U8.6, U8.8, U9.8, U10.8, U11.7, U12.7, U13.7, U14.7, U15.7, U16.7, U17.8, U18.8, U19.8, U20.7, U21.8, U22.7, U23.7, U24.1, U24.10, U25.7, U26.7, U27.7, U28.7, U29.7, U30.7, U31.7, U32.1, U32.6, U32.8, U33.2, U33.14, U33.22, U33.23, U33.26, U33.27, U34.10, U35.10, U36.10, U37.10, U38.1, U39.8, U40.8, U41.7, U42.7, U42.13, U43.7, U44.7, U45.4, U45.7, U45.8, U46.7, U47.7, U48.7, U49.7, U50.8, U51.8, U52.8, U53.8, U54.8, U55.8, U56.8, U57.8, U58.10, U59.10, U60.10, U61.10, U62.7, U62.10, U62.13, U63.8, U64.7, U65.7, U66.10, U67.1, U67.10, U67.19, U68.7, U101.8
GRPH: U16.11, U22.13, U23.13, U40.5, U47.1, U48.12
G_OUT: C21.1, R12.2, U67.16
HCLK: U5.7, U6.9, U21.9, U27.3
HRES: U16.13, U27.2, U27.9, U30.5, U40.2, U47.3, U49.3
HSYNC: U21.6, U38.39
HSYNC_DLY: U21.7, U43.1, U64.9, U65.6
HSYNC_OUT: C32.1, J2.8, U67.9
I: U24.6, U67.8, U101.10
IO_CLOCK: P5.20, U11.11
IO_READY: P5.41, U62.6
I_OUT: C23.1, R14.2, U67.12
LCLK: U6.2, U27.5, U43.3, U64.8
LPEN_STR: U11.5, U24.15, U38.3
MD0: U34.18, U35.18, U36.18, U37.3, U57.2, U57.14
MD1: U34.17, U35.17, U36.16, U37.4, U56.2, U56.14
MD2: U34.14, U35.14, U36.14, U37.7, U55.2, U55.14
MD3: U34.13, U35.13, U36.12, U37.8, U54.2, U54.14
MD4: U34.8, U35.8, U36.9, U37.13, U53.2, U53.14
MD5: U34.7, U35.7, U36.7, U37.14, U52.2, U52.14
MD6: U34.4, U35.4, U36.5, U37.17, U51.2, U51.14
MD7: U34.3, U35.3, U36.3, U37.18, U50.2, U50.14
MUX_A: U9.14, U10.14, U23.8
MUX_B: U9.2, U10.2, U23.11
unnamed: J2.3, R11.1
unnamed: J2.4, R12.1
unnamed: J2.5, R13.1
unnamed: J2.6, R14.1
unnamed: P5.62, U13.4, U13.5
unnamed: Q1.1, R1.2, R4.2
unnamed: Q1.2, R5.1, R6.1, R7.1, R8.1, R17.1, R18.1, R19.1, R20.2
unnamed: R5.2, U24.18
unnamed: R6.2, U24.16
unnamed: R7.2, U24.14
unnamed: R8.2, U24.12
unnamed: R18.2, U67.3
unnamed: R19.2, U67.5
unnamed: U1.5, U46.5, U46.13
unnamed: U1.6, U46.2, U46.10
unnamed: U1.9, U3.9
unnamed: U1.12, U26.4
unnamed: U2.6, U28.4, U47.2
unnamed: U2.10, U29.6
unnamed: U2.5, U2.12
unnamed: U2.4, U2.9, U2.13
unnamed: U3.1, U5.5, U6.11
unnamed: U3.3, U30.10
unnamed: U3.8, U31.1
unnamed: U3.12, U4.5, U4.6, U49.2
unnamed: U4.7, U4.11
unnamed: U4.15, U5.3
unnamed: U5.10, U6.5
unnamed: U5.13, U6.4
unnamed: U5.15, U6.3
unnamed: U10.7, U101.6
unnamed: U10.9, U101.11
unnamed: U10.11, U31.8
unnamed: U11.1, U17.12
unnamed: U11.3, U29.4
unnamed: U11.4, U17.11
unnamed: U11.12, U11.13, U15.8, U16.1
unnamed: U12.2, U12.12, U65.13
unnamed: U13.1, U15.3
unnamed: U13.9, U29.10
unnamed: U13.11, U14.4
unnamed: U13.12, U14.3
unnamed: U14.1, U28.8
unnamed: U14.5, U49.13
unnamed: U14.8, U41.4
unnamed: U14.11, U65.8
unnamed: U14.12, U20.10
unnamed: U14.13, U43.5
unnamed: U15.2, U21.5, U21.14
unnamed: U15.4, U15.5, U43.2, U64.13
unnamed: U15.6, U42.9
unnamed: U15.11, U28.1
unnamed: U15.12, U16.3, U40.12
unnamed: U16.2, U17.4, U65.3
unnamed: U16.4, U22.12, U23.5
unnamed: U16.9, U22.3, U29.9, U40.7
unnamed: U17.5, U18.7, U30.2, U65.2
unnamed: U18.6, U41.3
unnamed: U19.5, U41.11
unnamed: U20.2, U21.3
unnamed: U20.5, U22.6
unnamed: U20.11, U64.12
unnamed: U20.12, U24.2
unnamed: U20.13, U42.6
unnamed: U21.2, U21.13
unnamed: U22.1, U23.3
unnamed: U22.8, U23.9
unnamed: U23.4, U26.8
unnamed: U23.6, U28.13
unnamed: U24.8, U45.5
unnamed: U25.1, U25.11, U48.5
unnamed: U25.9, U30.6
unnamed: U25.3, U25.12, U48.3
unnamed: U25.13, U26.10
unnamed: U26.5, U46.9, U46.12, U47.6
unnamed: U26.6, U46.1, U46.4
unnamed: U26.9, U48.6
unnamed: U28.2, U65.4
unnamed: U28.3, U29.2
unnamed: U28.5, U49.4
unnamed: U29.11, U65.1
unnamed: U29.12, U31.2
unnamed: U30.9, U49.1
unnamed: U32.2, U33.11
unnamed: U32.3, U33.12
unnamed: U32.4, U33.13
unnamed: U32.5, U33.15
unnamed: U32.10, U33.16
unnamed: U32.11, U33.17
unnamed: U32.12, U33.18
unnamed: U32.14, U33.19
unnamed: U33.20, U68.11
unnamed: U38.4, U59.3
unnamed: U38.5, U59.4
unnamed: U38.6, U59.7
unnamed: U38.7, U59.8
unnamed: U38.8, U59.13
unnamed: U38.9, U59.14
unnamed: U38.10, U59.17
unnamed: U38.11, U58.3
unnamed: U38.12, U58.4
unnamed: U38.13, U58.7
unnamed: U38.14, U58.8
unnamed: U38.15, U58.13
unnamed: U38.16, U48.9
unnamed: U41.6, U66.1
unnamed: U41.8, U42.4, U67.13
unnamed: U41.9, U63.2, U63.5
unnamed: U41.10, U63.14
unnamed: U5.6, U42.3
unnamed: U42.5, U63.9, U64.4, U67.11
unnamed: U42.8, U64.1
unnamed: U42.10, U64.6
unnamed: U45.9, U68.6
unnamed: U45.10, U68.3
unnamed: U48.8, U49.8, U49.9
unnamed: U49.10, U58.14
unnamed: U62.8, U62.12
unnamed: U63.10, U63.13
unnamed: U63.7, U63.12
unnamed: U65.10, U68.2, U68.5
unnamed: U68.8, U68.12
unnamed: U9.7, U101.3
unnamed: U9.9, U101.4
unnamed: U101.12, U101.14
OVERSCAN_B: U10.3, U39.2
OVERSCAN_G: U9.13, U39.5
OVERSCAN_I: U10.13, U39.10
OVERSCAN_R: U9.3, U39.7
Q1: U2.3, U3.4, U5.2, U5.4, U47.4, U60.11, U61.11
Q4: U3.13, U4.10, U4.13, U42.2, U68.10
Q5: U1.11, U4.12, U4.14, U26.3, U49.6
R: U67.2, U67.17, U68.4, U101.2
RA0: U33.10, U38.38, U48.1
RA1: U33.9, U38.37
RA2: U33.8, U38.36
RAS: U1.3, U3.6, U26.1
RESET: P5.2, U20.9, U68.13
R_OUT: C20.1, R11.2, U67.18
SEL_BLUE: U10.4, U20.6
SL: U7.15, U8.15, U32.15, U62.11
SL': U30.8, U62.9
STR: U9.1, U9.15, U10.1, U10.15, U28.12
VCC: C1.2, C2.2, C3.2, C4.2, C5.2, C6.2, C7.2, C8.2, C9.2, C10.2, C11.2, C12.2, C13.2, C14.2, C15.2, C16.2, C17.2, C18.2, C19.2, C26.1, C27.1, C28.2, C29.2, C30.2, C33.2, C34.2, C35.2, C36.2, C37.2, C38.2, C39.2, C40.2, C41.2, C42.2, C43.2, C44.2, C45.2, C46.2, C47.2, C48.2, C49.2, C51.2, C52.2, C53.2, C54.2, C55.2, C56.2, C57.2, C58.2, C59.2, C60.2, C61.2, C62.2, C63.2, C64.2, C65.2, C66.2, C67.2, C68.2, C69.2, C70.2, C71.2, C72.2, C73.2, C74.2, C75.2, C76.2, C77.2, C78.2, C79.2, C80.2, P2.5, P5.3, P5.29, Q1.3, R20.1, U1.4, U1.10, U1.14, U1.15, U1.16, U2.1, U2.14, U3.14, U4.16, U5.16, U6.14, U7.16, U8.16, U9.16, U10.16, U11.2, U11.10, U11.14, U12.14, U13.14, U14.14, U15.14, U16.14, U17.16, U18.16, U19.16, U20.14, U21.1, U21.16, U22.9, U22.14, U23.14, U24.20, U25.14, U26.14, U27.10, U27.13, U27.14, U28.14, U29.14, U30.14, U31.14, U32.16, U33.1, U33.28, U34.1, U34.20, U35.20, U36.20, U37.20, U38.20, U39.16, U40.16, U41.14, U42.14, U43.14, U44.14, U45.12, U45.16, U46.14, U47.10, U47.13, U47.14, U48.10, U48.13, U48.14, U49.14, U50.16, U51.16, U52.16, U53.16, U54.16, U55.16, U56.16, U57.16, U58.20, U59.20, U60.20, U61.20, U62.14, U63.4, U63.16, U64.2, U64.14, U65.14, U66.20, U67.20, U68.14, U101.1, U101.16
VIDEO_ENABLE: U13.2, U40.10
VSYNC: U21.11, U38.40
VSYNC_DLY: U12.1, U21.10, U24.11, U63.1, U65.5, U65.9
VSYNC_OUT: C31.1, J2.9, U67.7
XACK: U2.8, U37.11, U62.5
~7_MHZ: U5.11, U6.6, U27.1
~14_MHZ: U6.12, U27.11, U44.11, U101.9
~6845_CS: U30.3, U38.25
~BLINK: U12.11, U14.2
~BW_1: U29.8, U44.1, U44.4, U44.10, U44.13
~BW_2: U16.8, U22.5, U43.4, U43.10, U43.13
~CAS: U31.3, U50.15, U51.15, U52.15, U53.15, U54.15, U55.15, U56.15, U57.15
~CCLK: U27.6, U30.4, U38.21, U47.11
~CLR_SR: U7.9, U8.9, U13.3, U32.9, U35.1
~CPU_MEM_SEL: U2.2, U13.10, U19.7, U29.5, U30.12, U62.4
~CURSOR_BLINK: U12.6, U12.13, U49.12
~CURSOR_DLY: U21.12, U28.9, U49.11
~DISPEN: U20.4, U21.4, U24.17
~DISPEN_DLY: U15.1, U15.13, U21.15, U23.10, U23.12
~ENABLE_BLINK: U16.6, U31.10
~EN_CPU_CAS_ADDR: U46.6, U61.1
~EN_CPU_RAS_ADDR: U46.3, U60.1
~EN_CRT_CAS_ADDR: U46.11, U58.1, U62.1
~EN_CRT_RAS_ADDR: U46.8, U59.1
~GRPH: U16.10, U22.10, U47.9, U48.11
~HCLK: U6.8, U62.2
~HRES: U16.12, U27.4, U27.12, U47.5
~IOR: P5.14, U14.10, U15.9
~IOW: P5.13, U15.10, U38.22
~LCLK: U3.2, U3.5, U3.10, U4.2, U4.4, U6.1, U68.9
~LPEN_INPUT: P2.1, U29.3
~LPEN_SW: P2.3, U24.13
~MEMR: U30.13, U41.5, U41.12, U42.11
~MEMW: P5.11, U29.1, U41.13
~Q2': U4.3, U6.10, U42.1, U47.12, U49.5
~RAS: U1.2, U2.11, U26.2, U50.4, U51.4, U52.4, U53.4, U54.4, U55.4, U56.4, U57.4, U58.11, U59.11
~RD_GATE: U30.11, U37.1
~RESET: U4.1, U5.1, U38.2, U39.1, U40.1, U101.15
~RESET': U20.8, U65.11, U65.12, U101.13
~SEL_1: U17.15, U40.9
~SEL_2: U17.14, U39.9
~STATUS_SEL: U17.13, U24.19
~WE: U28.6, U36.1, U36.19, U50.3, U51.3, U52.3, U53.3, U54.3, U55.3, U56.3, U57.3

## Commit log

2021-03-08 Add empty project
    [ISA_CGA.kicad_pcb, ISA_CGA.sch]
2021-03-08 Begin drawing first sheet of CGA
    [CGA_1_6.sch, CGA_2_6.sch, CGA_3_6.sch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]
2021-03-08 Complete a sheet
    [CGA_1_6.sch, ISA_CGA.sch]
2021-03-08 Remove char from label
    [CGA_1_6.sch]
2021-03-09 Begin 2nd sheet
    [CGA_2_6.sch]
2021-03-09 More drawings of sheet 2
    [CGA_2_6.sch]
2021-03-09 More sheet 2
    [CGA_2_6.sch]
2021-03-09 More sheet 2
    [CGA_2_6.sch]
2021-03-09 Move some components
    [CGA_2_6.sch]
2021-03-09 More of sheet 2
    [CGA_2_6.sch]
2021-03-10 Added MK36000 symbol
    [CGA_2_6.sch]
2021-03-10 More sheet 2 changes
    [CGA_2_6.sch]
2021-03-10 Resized sheet
    [CGA_2_6.sch]
2021-03-10 Added power for ICs in sheet 2
    [ISA_CGA.sch]
2021-03-10 Begin drawing sheet 3/6
    [CGA_3_6.sch, ISA_CGA.sch]
2021-03-10 More sheet 3 drawing
    [CGA_3_6.sch]
2021-03-10 More sheet 3
    [CGA_3_6.sch]
2021-03-11 Sheet 3
    [CGA_3_6.sch]
2021-03-11 Cleanup more sheet 3
    [CGA_3_6.sch]
2021-03-11 Cleanup sheet
    [CGA_3_6.sch]
2021-03-11 Power connection for more units
    [ISA_CGA.sch]
2021-03-11 more sheets
    [ISA_CGA.sch]
2021-03-11 More power inputs
    [ISA_CGA.sch]
2021-03-11 Begin sheet 4
    [CGA_4_6.sch]
2021-03-11 More sheet 4
    [CGA_4_6.sch]
2021-03-11 More CGA sheet 4
    [CGA_4_6.sch]
2021-03-11 Some more sheet 4
    [CGA_4_6.sch]
2021-03-12 Add more of sheet 4
    [CGA_4_6.sch]
2021-03-13 Sheet 4
    [CGA_4_6.sch]
2021-03-13 Begin sheet 5
    [CGA_5_6.sch]
2021-03-13 More sheet 5
    [CGA_5_6.sch]
2021-03-14 Sheet 5
    [CGA_5_6.sch]
2021-03-14 More power connections for sheet 5
    [ISA_CGA.sch]
2021-03-14 Add some components to sheet 6
    [CGA_6_6.sch]
2021-03-14 More sheet 6
    [CGA_6_6.sch]
2021-03-14 Sheet 6
    [CGA_6_6.sch, ISA_CGA.sch]
2021-03-14 Update board
2021-03-15 Fix some label types in sheet 1
    [CGA_1_6.sch]
2021-03-15 Fix some more label types
    [CGA_2_6.sch]
2021-03-19 Add missing connection to Vcc/GND for two ICs
    [ISA_CGA.sch]
2021-03-20 Fix one of the gates of U15 on sheet 3
    [CGA_3_6.sch]
2021-03-20 Fixed some duplicate units and mislabeling
    [CGA_1_6.sch, CGA_2_6.sch, CGA_3_6.sch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]
2021-03-20 Fix RAM bus connections
    [CGA_1_6.sch]
2021-03-20 Fix some more flags and footprints
    [CGA_1_6.sch, CGA_2_6.sch, CGA_3_6.sch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]
2021-03-21 Cleanup schematics a bit
    [CGA_5_6.sch]
2021-03-25 Update note on caps at the RGBI connector
    [CGA_5_6.sch]
2021-03-25 Reorganize DRAM address lines
    [CGA_1_6.sch]
2021-03-25 Added note on RAM chips
    [CGA_1_6.sch]
2021-03-28 Add note on light pen input and change the label types
    [CGA_6_6.sch]
2021-03-29 Add extra libraries and assign footprints
    [CGA_6_6.sch]
2021-03-29 Replace MK36000 with 27C256
    [CGA_2_6.sch]
2021-03-29 Begin preparing board
    [ISA_CGA.kicad_pcb]
2021-03-29 Fixed some footprints
    [CGA_2_6.sch, CGA_6_6.sch, ISA_CGA.kicad_pcb]
2021-04-02 Add filter caps for every IC
    [CGA_6_6.sch, ISA_CGA.kicad_pcb]
2021-04-02 Begin laying out ICs
    [ISA_CGA.kicad_pcb]
2021-04-02 Laying out more components
    [CGA_6_6.sch, ISA_CGA.kicad_pcb, ISA_CGA.sch]
2021-04-02 Additional layout
    [ISA_CGA.kicad_pcb]
2021-04-02 Reorganize space between ICs
    [CGA_1_6.sch, CGA_5_6.sch, CGA_6_6.sch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]
2021-04-02 More layout
    [ISA_CGA.kicad_pcb]
2021-04-02 Reorganize layout a bit
    [ISA_CGA.kicad_pcb]
2021-04-02 Place some more ICs
    [ISA_CGA.kicad_pcb]
2021-04-02 Place more components
    [ISA_CGA.kicad_pcb]
2021-04-02 place all components
    [ISA_CGA.kicad_pcb]
2021-04-02 Add mask
    [ISA_CGA.kicad_pcb]
2021-04-02 Close board outline
    [ISA_CGA.kicad_pcb]
2021-04-02 Changed footprints, moving components
    [CGA_1_6.sch, CGA_2_6.sch, CGA_3_6.sch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]
2021-04-02 Redone layout
    [ISA_CGA.kicad_pcb]
2021-04-02 Route power tracks in inner layers
    [ISA_CGA.kicad_pcb]
2021-04-02 Moved some components
    [ISA_CGA.kicad_pcb]
2021-04-02 Add keepout areas for autorouter
    [ISA_CGA.kicad_pcb]
2021-04-02 Added copper fill zones
    [ISA_CGA.kicad_pcb]
2021-04-03 Fix connections in power plane
    [ISA_CGA.kicad_pcb]
2021-04-03 Added some silkscreen
    [ISA_CGA.kicad_pcb]
2021-04-03 Add some more silkscreen entries
    [ISA_CGA.kicad_pcb]
2021-04-03 More silkscreen, slightly move component
    [ISA_CGA.kicad_pcb]
2021-04-03 More silkscreen
    [ISA_CGA.kicad_pcb]
2021-04-04 Commit PCB before importing the routed traces
    [ISA_CGA.kicad_pcb]
2021-04-04 Imported traces
2021-04-07 Fixed wrong DRAM pinout
    [CGA_5_6.sch]
2021-04-07 connect the two NC in DRAM to GND, so ideally 4164 and 41256 can be used
    [CGA_1_6.sch]
2021-04-19 Rewire 27C256 so a dump from the original MK36000 can be used unchanged
    [CGA_2_6.sch]
2021-04-27 Reroute tracks to edge connector
2021-04-27 Reroute backside traces to edge connector
2021-05-25 Add some more grounding
2021-05-27 Add rev 1.0 gerbers
2021-05-28 Add fatter power traces, added gerbers for rev.0
2021-06-09 Replaced RCA jack
    [CGA_6_6.sch]
2021-06-10 Fix power trace running below composite connector
2021-06-10 Replaced 74LS10 for U28 with 74S10
    [CGA_1_6.sch, CGA_2_6.sch, CGA_4_6.sch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]
2021-06-13 Add rev 0.1 gerbers, further noted in readme
2021-06-13 Begin working on rev 0.2, for an easier "old" composite out mod
    [CGA_2_6.sch, CGA_4_6.sch, CGA_5_6.sch]
2021-06-13 Added silkscreen to tick the type of composite build
2021-06-15 Add "old" Composite mod values to silkscreen on back
2021-06-17 Renamed components, cleaned the silkscreen
    [CGA_6_6.sch]
2021-06-17 Generate gerbers for rev 0.2
2021-11-09 Update KiCad url
2022-10-26 Add datasheet with information about the bracket
2023-10-13 Initial import of the board in Kicad 7
    [CGA_1_6.kicad_sch, CGA_2_6.kicad_sch, CGA_3_6.kicad_sch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]
2023-10-13 Fix some junctions
    [ISA_CGA.kicad_sch, ISA_CGA.sch]
2024-08-01 Remove backups by kicad...
2026-06-20 Fix Q1' naming thanks to Michael Karcher
    [CGA_1_6.kicad_sch, CGA_2_6.kicad_sch, CGA_3_6.kicad_sch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]
